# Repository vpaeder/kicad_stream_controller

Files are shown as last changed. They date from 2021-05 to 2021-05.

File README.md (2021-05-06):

# Fichiers KiCad pour mon stream twitch d'électronique absconse
Pour en savoir plus, venez me dire coucou sur https://twitch.tv/cannetier .

Le but du projet étant mouvant, il risque que ça meuve. A ce stade néanmoins, je me dirige vers un petit boitier pour contrôler <insérer votre choix ici> avec les fonctionalités suivantes :
 - connection USB ou sans fil par bluetooth ou wifi
 - écran tactile
 - dans la v1, deux potentiomètres intégrés (la v2 devrait être modulaire)
 - batterie intégrée
 - coeur ESP32
 - abordable (pour l'instant environ 75 euros avec le boitier et les frais de port, pour un prototype en 1 exemplaire)

J'en suis à la v1 qui est censée être assez facile à fabriquer.
La v2 devrait être modulaire avec la possibilité de rajouter des blocs en chaîne sur les côtés. J'ai déjà créé un repo avec les fichiers OpenSCAD pour le boitier ici : https://github.com/vpaeder/openscad_modbox

Voilà quelques images pour donner une idée du résultat :
Aperçu du modèle - vue de face
Aperçu du modèle - vue de dos
Aperçu du modèle - vue interne

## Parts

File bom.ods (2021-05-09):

Mfr part # | Function | Qty | Unit price Ex. VAT (€) | Total price Ex. VAT (€)
Electronics (prices from Digikey, 25/03/2021)
MCP2221A-I/SL | USB 2.0 to I2C/UART Protocol Converter with GPIO | 1 | 1.8 | 1.8
MCP73831T-2ACI/OT | Single Cell, Li-Ion/Li-Polymer Charge Management Controller | 1 | 0.49 | 0.49
ESP32-WROVER-E (16MB) | WiFi 802.11b/g/n Transceiver Module 2.4GHz | 1 | 3.22 | 3.22
NHD-2.4-240320CF-BSXV-FT | Resistive Graphic LCD Display Module Transmissive RGB TFT Color SPI 2.4" (60.96mm) 240 x 320 | 1 | 20.26 | 20.26
FFC3B11-20-T | 20 Position FFC, FPC Connector Contacts, Top 0.039" (1.00mm) | 1 | 0.37 | 0.37
10118193-0001LF | USB - micro B USB 2.0 Receptacle Connector 5 Position Surface Mount, Right Angle; Through Hole | 1 | 0.4 | 0.4
PMZ320UPEYL | P-Channel 30V 1A (Ta) 350mW (Ta), 6.25W (Tc) | 1 | 0.195 | 0.195
BSS84AK,215 | P-Channel 50V 180mA (Ta) 350mW (Ta), 1.14W (Tc) Surface Mount TO-236AB | 1 | 0.16 | 0.16
P160KNPD-2QC25B2K | 2k Ohm 1 Gang Linear Panel Mount Potentiometer Detent 1 Kierros Conductive Plastic 0.2W, 1/5W PC Pins | 2 | 0.66 | 1.32
2048 | Ribbed Knob Shaft with Line on Top and Side Blue | 2 | 0.41 | 0.82
CL05A474KP5NNNC | 0.47µF ±10% 10V Ceramic Capacitor X5R 0402 (1005 Metric) | 1 | 0.023 | 0.023
CL05A104KA5NNNC | 0.1µF ±10% 25V Ceramic Capacitor X5R 0402 (1005 Metric) | 3 | 0.0256 | 0.0768
MCP1825ST-3302E/DB | Linear Voltage Regulator IC Positive Fixed 1 Output 500mA SOT-223-3 | 1 | 0.45 | 0.45
CM05X5R475M10AH | 4.7µF ±20% 10V Ceramic Capacitor X5R 0402 (1005 Metric) | 3 | 0.0712 | 0.2136
CR0402-JW-103GLF | 10 kOhms ±5% 0.063W, 1/16W Chip Resistor 0402 (1005 Metric) Thick Film | 4 | 0.0013 | 0.0052
SS24-HF | Diode Schottky 40V 2A Surface Mount DO-214AC (SMA) | 1 | 0.211 | 0.211
CR0402-FX-2001GLF | 2 kOhms ±1% 0.063W, 1/16W Chip Resistor 0402 (1005 Metric) Thick Film | 3 | 0.0034 | 0.0102
DDZ5V6ASF-7 | Zener Diode 5.42V 500mW ±2% Surface Mount SOD-323F | 1 | 0.094 | 0.094
MIC803-30D2VM3-TR | Supervisor Open Drain or Open Collector 1 Channel SOT-23-3 | 1 | 0.25 | 0.25
CR0402-JW-104GLF | 100 kOhms ±5% 0.063W, 1/16W Chip Resistor 0402 (1005 Metric) Thick Film | 3 | 0.0067 | 0.0201
GF-126-0331 | Slide Switch SPDT Through Hole | 1 | 0.86 | 0.86
ESD9X5.0ST5G | 12.3V Clamp 8.7A (8/20µs) Ipp Tvs Diode Surface Mount SOD-923 | 3 | 0.168 | 0.504
CR0402-JW-2R0GLF | 2 Ohms ±5% 0.063W, 1/16W Chip Resistor 0402 (1005 Metric) Thick Film | 1 | 0.0064 | 0.0064
CLM-101-02-L-D | 2 Position Receptacle Connector 0.039" (1.00mm) Surface Mount Gold | 1 | 0.43 | 0.43
PCB (price from Aisler.net for 3 units, 25/03/2021)
 | PCB | 1 | 5.274 | 5.274
Battery and screws (prices from Hobby King, 25/03/2021)
171001209-0 | Screw Flat Head Phillips M3x10mm Self Tapping Steel Black | 4 | 0.059 | 0.236
Z850S20C | ZIPPY 850mAh 20C single cell | 1 | 2.9 | 2.9
Box parts (prices from Sculpteo, in multijet PA12, 25/03/2021)
 | Box back | 1 | 5.53 | 5.53
 | Box top | 1 | 11.36 | 11.36
 | Box support | 1 | 7.63 | 7.63
 |  |  | Total Ex. VAT (€) | 65.1193

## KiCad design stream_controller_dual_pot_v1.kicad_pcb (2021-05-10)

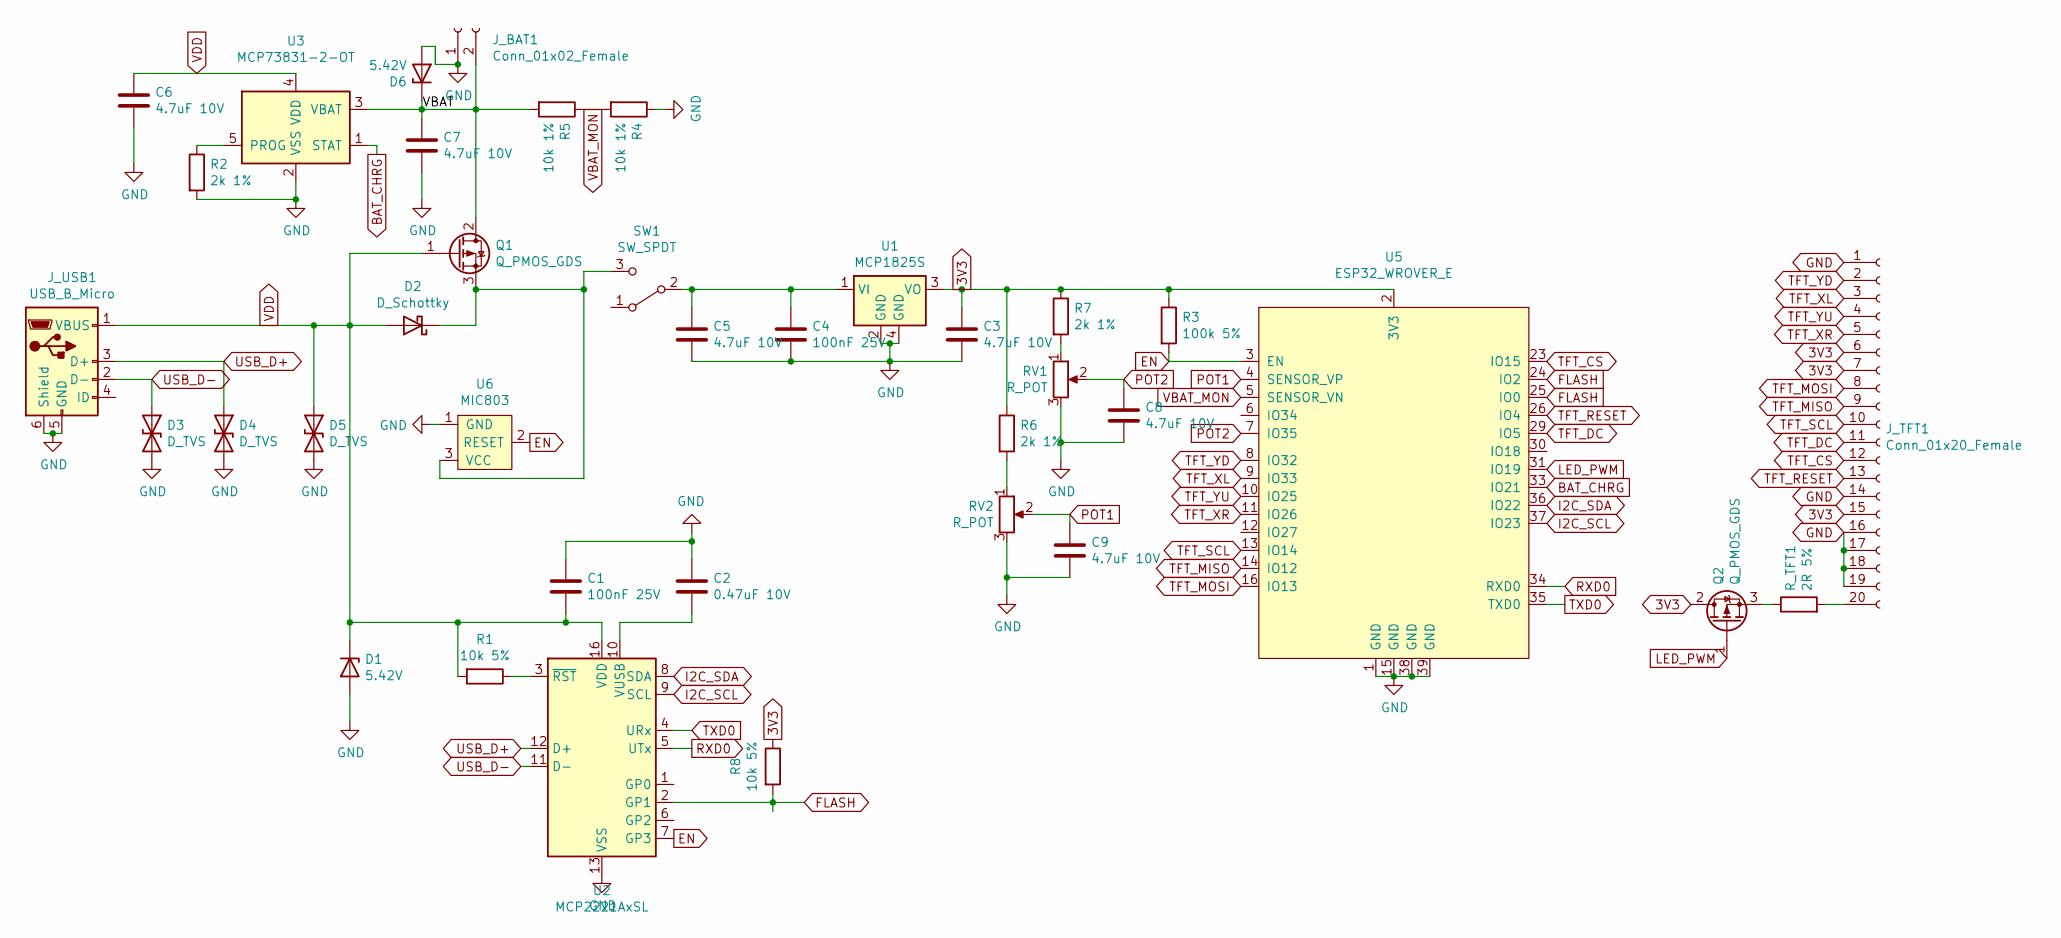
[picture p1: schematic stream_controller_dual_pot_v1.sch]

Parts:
C1, C4: 100nF 25V; C_0402_1005Metric_Pad0.74x0.62mm_HandSolder
C2: 0.47uF 10V; C_0402_1005Metric_Pad0.74x0.62mm_HandSolder
C3, C5, C6, C7, C8, C9: 4.7uF 10V; C_0402_1005Metric_Pad0.74x0.62mm_HandSolder
D1, D6: 5.42V; D_SOD-323F
D2: D_Schottky; D_SMA
D3, D4, D5: D_TVS; D_SOD-523
J_BAT1: Conn_01x02_Female; PinHeader_1x02_P2.54mm_Vertical
J_TFT1: Conn_01x20_Female; FFC3B11-20-T
J_USB1: USB_B_Micro; 10118193-0001LF
Q1: Q_PMOS_GDS; Diodes_DFN1006-3
Q2: Q_PMOS_GDS; SOT-23
R1, R8: 10k 5%; R_0402_1005Metric_Pad0.72x0.64mm_HandSolder
R2, R6, R7: 2k 1%; R_0402_1005Metric_Pad0.72x0.64mm_HandSolder
R3: 100k 5%; R_0402_1005Metric_Pad0.72x0.64mm_HandSolder
R4, R5: 10k 1%; R_0402_1005Metric_Pad0.72x0.64mm_HandSolder
RV1, RV2: R_POT; P160KNPD-4FC20B
R_TFT1: 2R 5%; R_0402_1005Metric_Pad0.72x0.64mm_HandSolder
SW1: SW_SPDT; GF-126-0331
U1: MCP1825S; SOT-223
U2: MCP2221AxSL; QFN-16-1EP_4x4mm_P0.65mm_EP2.5x2.5mm
U3: MCP73831-2-OT; SOT-23-5
U5: ESP32_WROVER_E; ESP32-WROVER-E
U6: MIC803; SOT-23

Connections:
3V3: C3.1, J_TFT1.6, J_TFT1.7, J_TFT1.15, Q2.2 (D), R3.1, R6.1, R7.1, R8.1, U1.3 (VO), U5.2 (3V3)
/VBAT: C7.1, D6.1 (K), J_BAT1.2, Q1.2 (D), R5.2, U3.3 (VBAT)
BAT_CHRG: U3.1 (STAT), U5.33 (IO21)
EN: R3.2, U2.7 (GP3), U5.3 (EN), U6.2 (RESET)
FLASH: R8.2, U2.2 (GP1), U5.24 (IO2), U5.25 (IO0)
GND: C1.1, C2.1, C3.2, C4.2, C5.2, C6.2, C7.2, C8.2, C9.2, D1.2 (A), D3.2 (A2), D4.2 (A2), D5.2 (A2), D6.2 (A), J_BAT1.1, J_TFT1.1, J_TFT1.14, J_TFT1.16, J_TFT1.17, J_TFT1.18, J_TFT1.19, J_TFT1.NC, J_USB1.5 (GND), J_USB1.6 (Shield), R2.2, R4.1, RV1.3, RV2.3, U1.2 (GND), U1.4 (GND), U2.13 (VSS), U3.2 (VSS), U5.1 (GND), U5.15 (GND), U5.38 (GND), U5.39 (GND), U6.1 (GND)
I2C_SCL: U2.9 (SCL), U5.37 (IO23)
I2C_SDA: U2.8 (SDA), U5.36 (IO22)
LED_PWM: Q2.1 (G), U5.31 (IO19)
unnamed: C2.2, U2.10 (VUSB)
unnamed: C4.1, C5.1, SW1.2 (B), U1.1 (VI)
unnamed: D2.1 (K), Q1.3 (S), SW1.3 (C), U6.3 (VCC)
unnamed: J_TFT1.20, R_TFT1.2
unnamed: Q2.3 (S), R_TFT1.1
unnamed: R1.1, U2.3 (~RST)
unnamed: R2.1, U3.5 (PROG)
unnamed: R6.2, RV2.1
unnamed: R7.2, RV1.1
POT1: C9.1, RV2.2, U5.4 (SENSOR_VP)
POT2: C8.1, RV1.2, U5.7 (IO35)
RXD0: U2.5 (UTx), U5.34 (RXD0)
TFT_CS: J_TFT1.12, U5.23 (IO15)
TFT_DC: J_TFT1.11, U5.29 (IO5)
TFT_MISO: J_TFT1.9, U5.14 (IO12)
TFT_MOSI: J_TFT1.8, U5.16 (IO13)
TFT_RESET: J_TFT1.13, U5.26 (IO4)
TFT_SCL: J_TFT1.10, U5.13 (IO14)
TFT_XL: J_TFT1.3, U5.9 (IO33)
TFT_XR: J_TFT1.5, U5.11 (IO26)
TFT_YD: J_TFT1.2, U5.8 (IO32)
TFT_YU: J_TFT1.4, U5.10 (IO25)
TXD0: U2.4 (URx), U5.35 (TXD0)
USB_D+: D4.1 (A1), J_USB1.3 (D+), U2.12 (D+)
USB_D-: D3.1 (A1), J_USB1.2 (D-), U2.11 (D-)
VBAT_MON: R4.2, R5.1, U5.5 (SENSOR_VN)
VDD: C1.2, C6.1, D1.1 (K), D2.2 (A), D5.1 (A1), J_USB1.1 (VBUS), Q1.1 (G), R1.2, U2.16 (VDD), U3.4 (VDD)

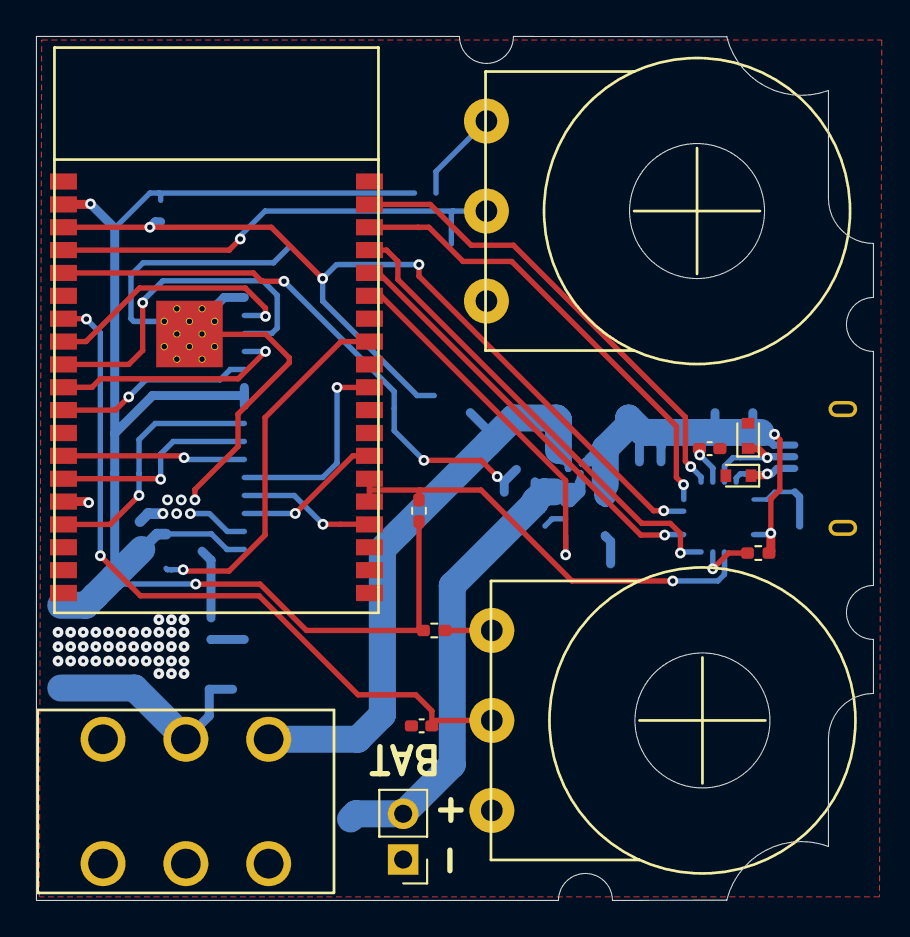
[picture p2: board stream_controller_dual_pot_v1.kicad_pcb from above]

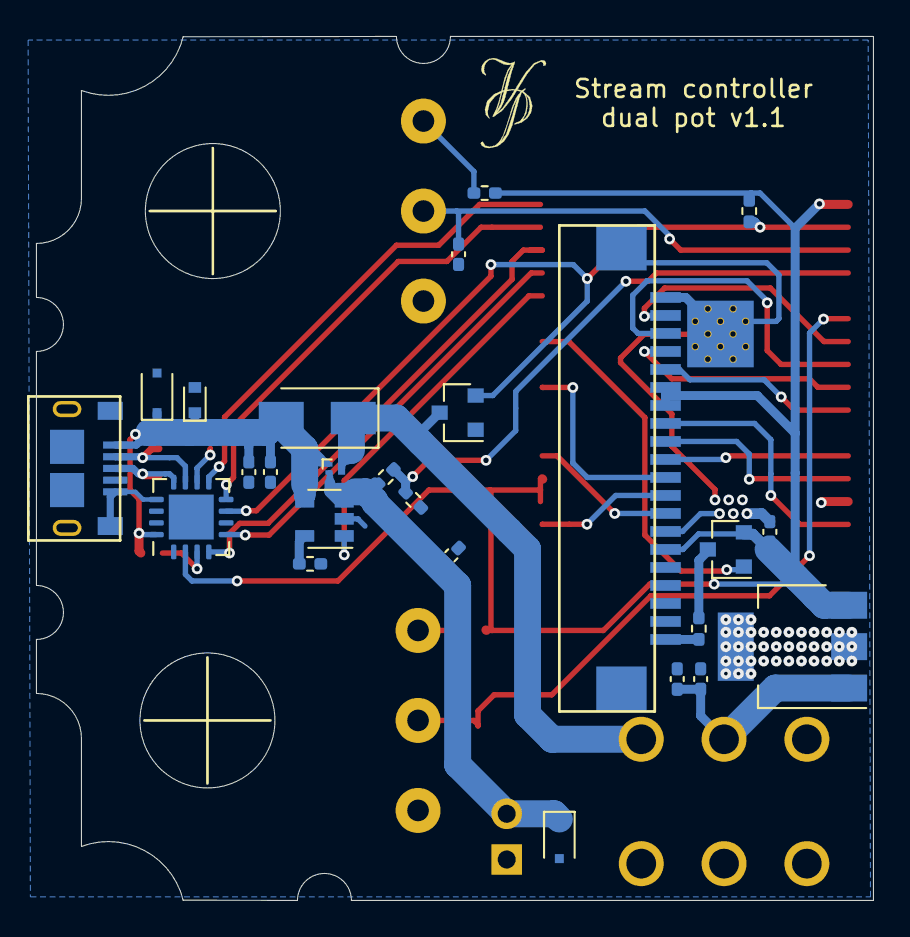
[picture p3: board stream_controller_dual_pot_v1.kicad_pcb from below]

Board: 2 copper layers, 46.5 x 48.0 mm, 37 parts (25 on the bottom side), 36 nets.

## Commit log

2021-05-04 bug UART corrigé
    [stream_controller_dual_pot_v1.kicad_pcb, stream_controller_dual_pot_v1.sch]
2021-05-06 Correction IO0 forcé à 1
    Si IO0 n'est pas haut au démarrage, l'ESP32 se met en mode flash. Quand non-connecté par USB, IO0 doit être forcé à 1, car le contrôleur USB n'est pas alimenté.
    [stream_controller_dual_pot_v1.kicad_pcb, stream_controller_dual_pot_v1.sch]
2021-05-06 Ajout contrôle pin EN par contrôleur USB
    [stream_controller_dual_pot_v1.kicad_pcb, stream_controller_dual_pot_v1.sch]
2021-05-06 Ajout BOM
    [bom.ods]
2021-05-09 Changements divers
    Modifications :
    - toutes les entrées analogiques sur ADC1, car ADC2 ne peut pas être utilisé si le WiFi est actif
    - lecture de l'écran tactile déplacée sur pattes 8, 9, 10 et 11, car les pattes 4, 5, 6 et 7 sont en lecture seule
    - changement du transistor pour le contrôle de la luminosité de l'écran
    [bom.ods, stream_controller_dual_pot_v1.kicad_pcb, stream_controller_dual_pot_v1.sch]
2021-05-10 Corrections et ajouts
    Corrigé : strapping pin 2 connectée au même signal FLASH que pin 0
    Ajouté : I2C entre uC et contrôleur USB
    [stream_controller_dual_pot_v1.kicad_pcb, stream_controller_dual_pot_v1.sch]
